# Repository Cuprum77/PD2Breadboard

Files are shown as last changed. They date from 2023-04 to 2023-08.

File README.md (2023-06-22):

# WORK IN PROGRESS - PD2Breadboard
Introducing the ultimate USB Power Delivery (PD) negotiator with unparalleled power measuring capabilities, powered by the cutting-edge RP2040 microcontroller. This isn't just any negotiator – it's a powerful variable power supply that's perfect for powering your breadboard projects on the fly, with an onboard high-resolution graphical LCD and three-button interface for easy control.

Our RP2040 powered USB PD negotiator is the perfect solution for anyone looking for a versatile, on-the-go power supply for their breadboard projects. With its advanced negotiating algorithm, this negotiator ensures optimal power delivery to your projects, while its onboard power measuring capabilities provide detailed insights into your device's power consumption.

The onboard high-resolution graphical LCD and three-button interface make it easy to control and monitor your device's power usage. With the graphical LCD, you can quickly view your device's power consumption and adjust the voltage levels to your desired level with the three-button interface.

Whether you're prototyping a new project, experimenting with electronics, or just need a reliable power source for your breadboard, our negotiator has you covered. It's capable of delivering up to 100W of power, with adjustable voltage levels ranging from 3.3V to 20V, making it compatible with a wide range of projects and devices.

And with its onboard power measuring capabilities, you'll have unprecedented insights into your device's power consumption. This feature is especially useful for those looking to optimize their device's power usage, or for those who want to monitor the power consumption of their projects in real-time.

Our RP2040 powered USB PD negotiator is also incredibly easy to use. Simply plug it into your USB port, set the voltage to your desired level using the graphical LCD and three-button interface, and let it power your breadboard project with ease. And with its compact, lightweight design, you can take it with you anywhere you go.

So why settle for a limited, fixed power supply when you can have the ultimate USB PD negotiator with onboard power measuring capabilities, variable voltage levels, and an onboard high-resolution graphical LCD and three-button interface? Take your breadboard projects to the next level!

## Technical Specifications
- RP2040 microcontroller
- 3.3V to 21V adjustable voltage levels[^1]
- 100W maximum power output[^2]
- 1.47" high-resolution graphical LCD
- 3-button interface
- USB Type-C connector
- Serial interface

[^1]: Requires a PPS capable device. The voltage levels are dependent on the power supply's capabilities.
[^2]: The maximum power output is dependent on the power supply's capabilities.

## Structure
### [Hardware](Hardware/)
The hardware folder contains all the hardware files for the project. This includes the schematic, PCB layout, and the BOM.
### [Resources](Resources/)
The resources folder contains all the resources for the project. This includes the datasheets, the user manuals, and the application notes. As well as images and other files that are used in the documentation.
### [Software/Embedded](Software/Embedded/)
The Folder contains all the software files for the microcontroller. This includes the source code, the libraries, and the relevant documentation.
### [Software/PC](Software/PC/)
The folder contains all the software files for the PC control program. This includes the source code, the libraries, and the relevant documentation.

## License
### Hardware
This hardware is licensed under the CERN Open Hardware Licence v2 - see the [LICENSE](Hardware/Rev%201/LICENSE) file for details
### Software
This software is licensed under the MIT License - see the [LICENSE](Software/Embedded/LICENSE) file for details

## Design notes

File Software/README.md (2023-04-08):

# PD2Breadboard Software
The RP2040 powered USB PD negotiator is not only a powerful variable power supply, but it also comes with a suite of advanced software features that set it apart from the competition. With power monitoring, self-diagnostics, and advanced algorithms, our software takes your breadboard projects to the next level.

The power monitoring feature allows you to keep an eye on your device's power consumption in real-time, providing detailed insights into your device's power usage. This feature is especially useful for those looking to optimize their device's power usage or for those who want to monitor the power consumption of their projects.

Our self-diagnostics feature ensures that your RP2040 powered USB PD negotiator is always functioning at peak performance. If any issues are detected, the software will provide detailed feedback, making it easy to diagnose and resolve any issues.

In addition to these features, our software is designed with ease of use in mind. The graphical user interface is intuitive and easy to navigate, making it easy to adjust the voltage levels and monitor power usage. And with its lightweight design, you can take it with you anywhere you go.

## Build
### Provided binaries
The provided binaries are located in the [build](build/) folder. The binaries are in the UF2 format, which can be flashed to the Pico using one of the two methods below.

### Programming via script
Dependencies:
* [Python 3](https://www.python.org/downloads/)

To build the project, simply run the `programmer.py` either using python or simply clicking the `programmer.bat` file if you are on Windows. The script will automatically install its own dependencies and transfer the code to the Pico.

### Programming manually
To program the pico there are two manual options

Using a Serial terminal:
* Using Serial to transmit the string "reset" will automatically put it in USB boot mode
* Manually drag and drop the UF2 file into the Pico drive from the build folder
Using the BOOTSEL button:
* Remove power from the Pico
* Press and hold the BOOTSEL button
* Reapply power to the Pico
* Release the BOOTSEL button
* Drag and drop the UF2 file into the Pico drive from the build folder

### Manually build the project
Dependencies:
* [VSCode](https://code.visualstudio.com/download)
* SDK [Windows](https://github.com/raspberrypi/pico-setup-windows/releases/latest/download/pico-setup-windows-x64-standalone.exe) | [Linux](https://github.com/raspberrypi/pico-sdk)

Follow the instructions on the SDK page to install the SDK. After installing the SDK, open the project in VSCode and build the project.

## Known Errors
### Version 1.0.0
* The debounce circuit, is supposed to form an RC circuit, but the pull-up resistor is placed on the wrong side of the current limiting resistor forming a voltage divider rather than an RC circuit. This means that the debounce circuit is not working as intended.
* Shunt resistor is too low value, this means we cannot get readings below 10mA. 

## License
This software is licensed under the MIT License - see the [LICENSE](LICENSE) file for details

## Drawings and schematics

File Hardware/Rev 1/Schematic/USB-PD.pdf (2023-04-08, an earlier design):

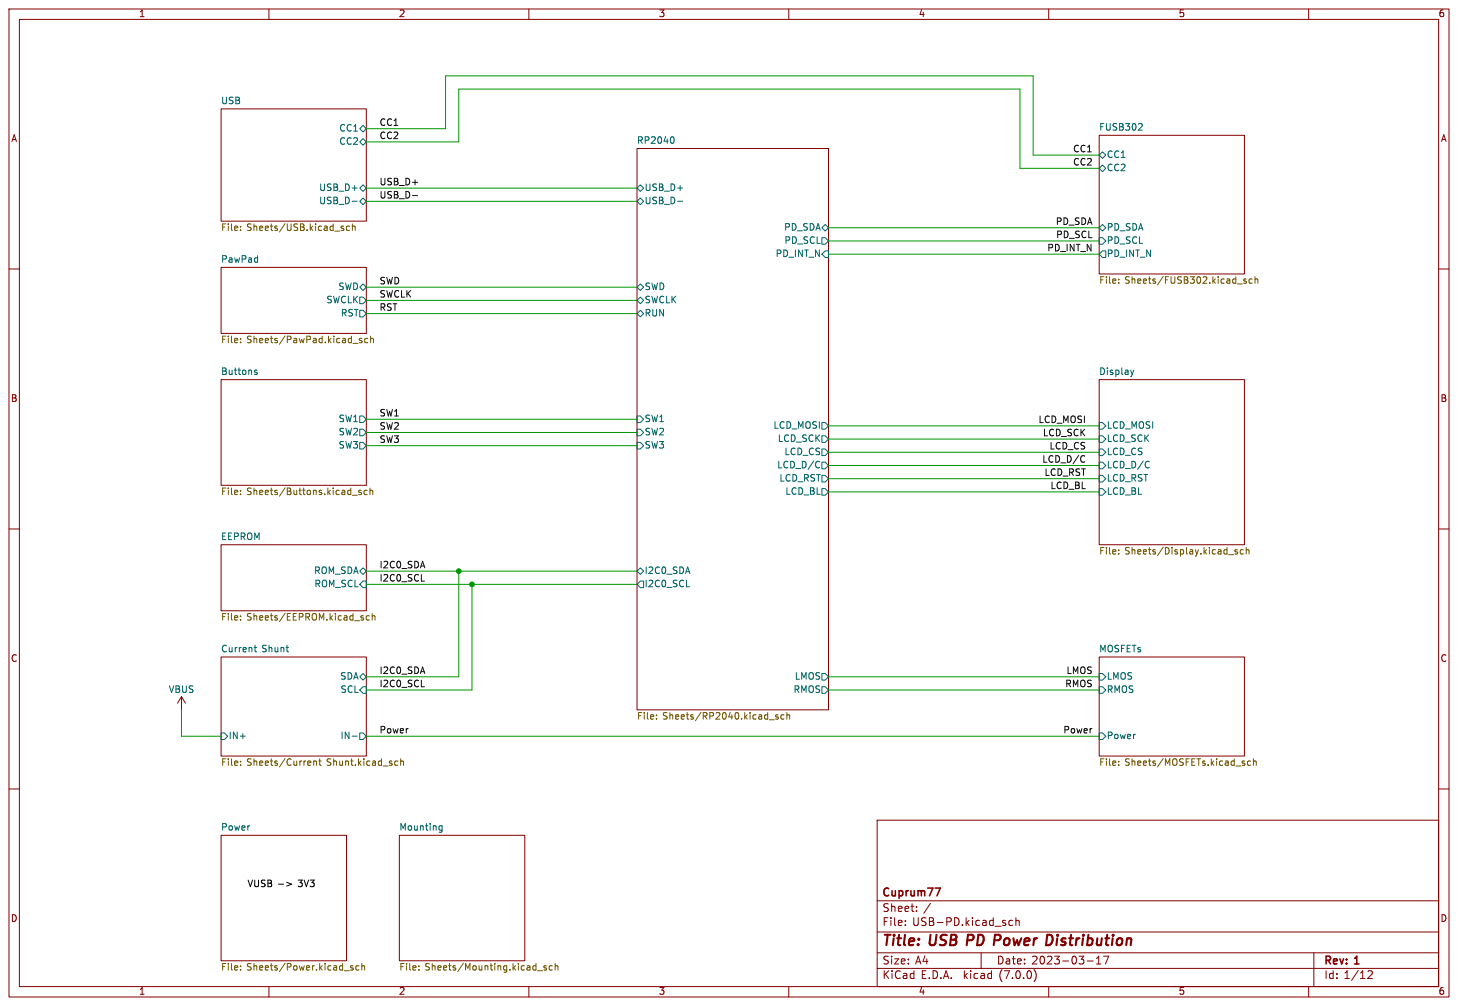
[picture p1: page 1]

SW3 SW2 SW1 Buttons File: Sheets/Buttons.kicad_sch USB_D- USB_D+ CC2 CC1 USB
LMOS RMOS RUN

RP2040 File: Sheets/RP2040.kicad_sch Power File: Sheets/Power.kicad_sch

Display File: Sheets/Display.kicad_sch SWD

File: Sheets/EEPROM.kicad_sch VBUS

Power MOSFETs File: Sheets/MOSFETs.kicad_sch

File: USB-PD.kicad_sch Sheet: / Cuprum77

Id: 1/12 Title: USB PD Power Distribution

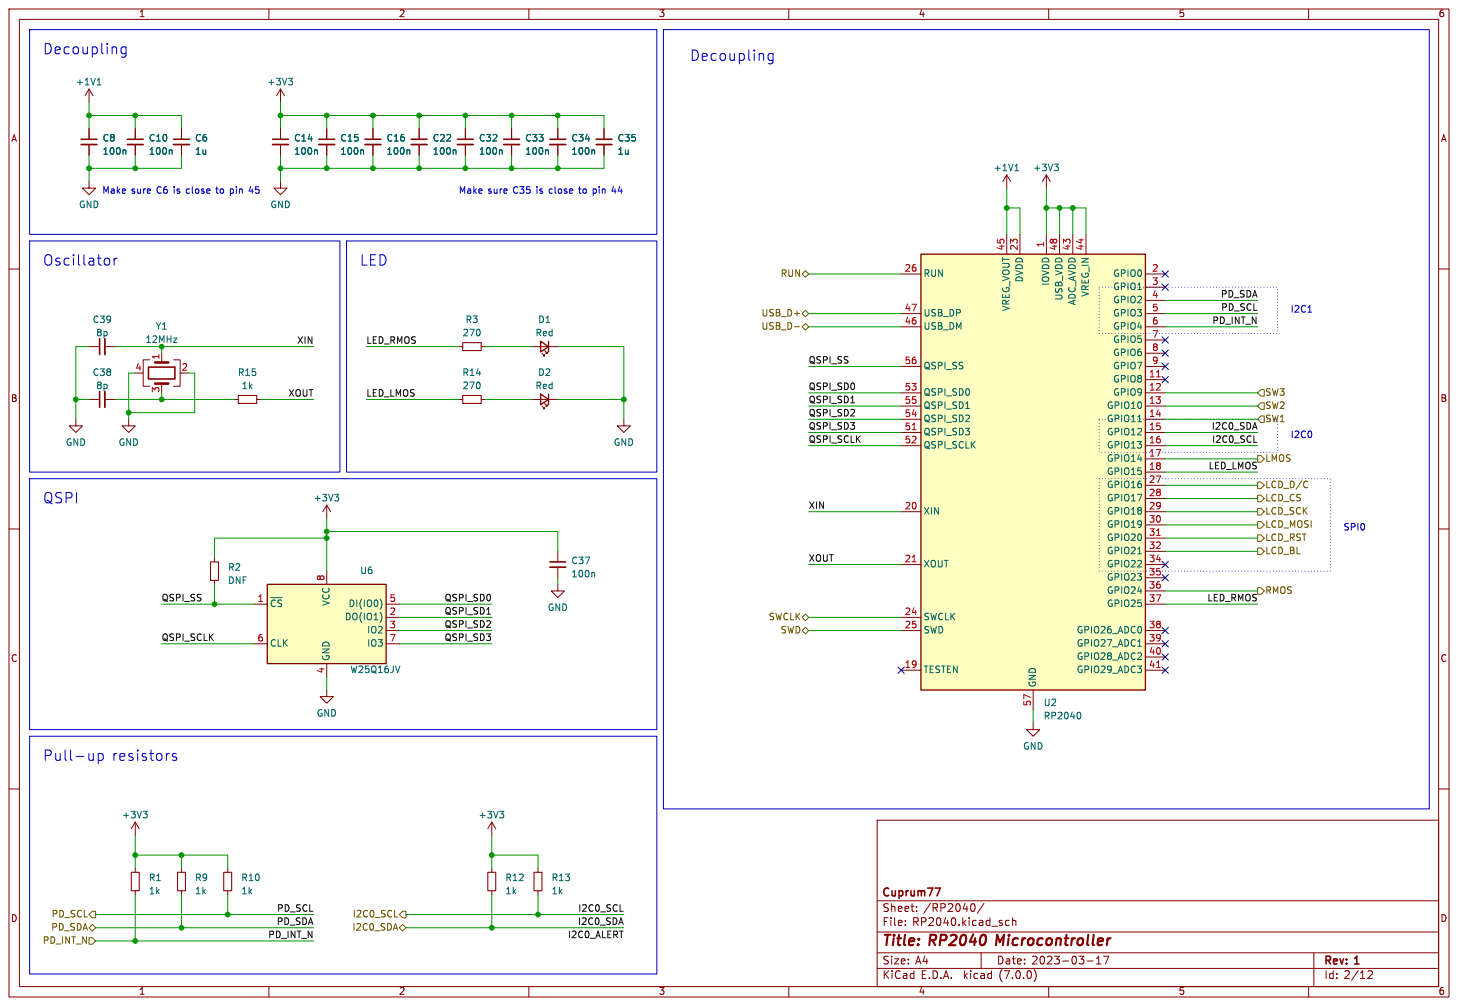
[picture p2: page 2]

1 GPIO8 11 GPIO9 12 GPIO10 13 GPIO11 14 GPIO12 15 GPIO13 16 GPIO14 17 GPIO15 18 TESTEN 19 GPIO0 2 XIN 20 XOUT 21 DVDD 23 SWCLK 24 SWD 25 RUN 26 GPIO16 27 GPIO17 28 GPIO18 29 GPIO1 3 GPIO19 30 GPIO20 31 GPIO21 32 GPIO22 34 GPIO23 35 GPIO24 36 GPIO25 37 GPIO26_ADC0 38 GPIO27_ADC1 39 GPIO2 4 GPIO28_ADC2 40 GPIO29_ADC3 41 ADC_AVDD 43 VREG_IN 44 VREG_VOUT 45 USB_DM 46 USB_DP 47 USB_VDD 48 GPIO3 5 QSPI_SD3 51 QSPI_SCLK 52 QSPI_SD0 53 QSPI_SD2 54 QSPI_SD1 55 QSPI_SS 56 GND 57 GPIO4 6 GPIO5 7 GPIO6 8 GPIO7 9 U2 RP2040

Id: 2/12 Title: RP2040 Microcontroller File: RP2040.kicad_sch Sheet: /RP2040/ Cuprum77

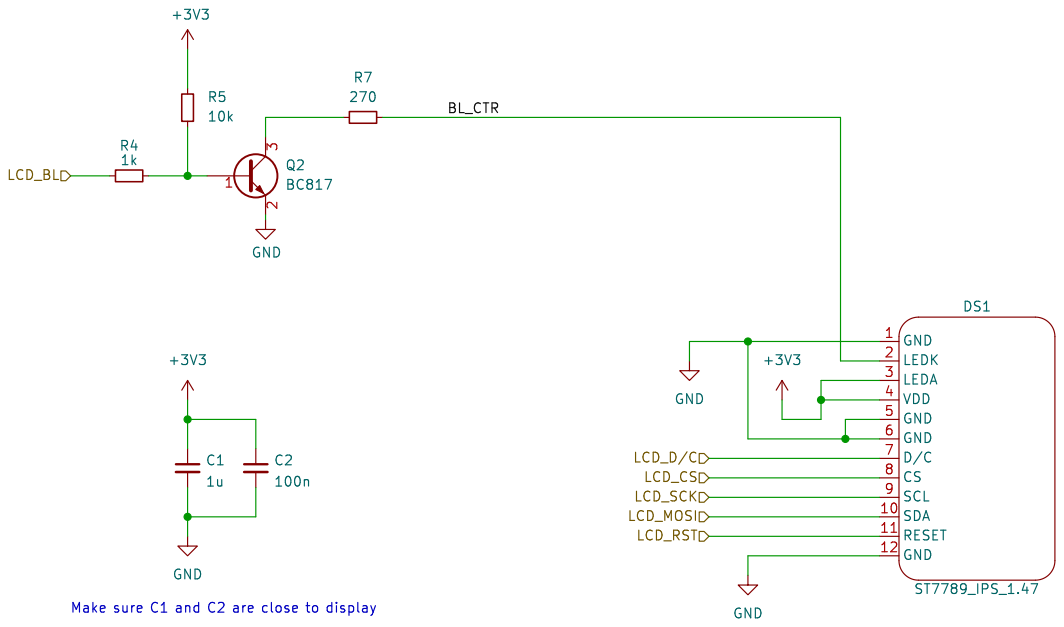
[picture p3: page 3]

LCD_RST BL_CTR Make sure C1 and C2 are close to display

Cuprum77
File: Display.kicad_sch Sheet: /Display/
Id: 3/12 Title: LCD Display

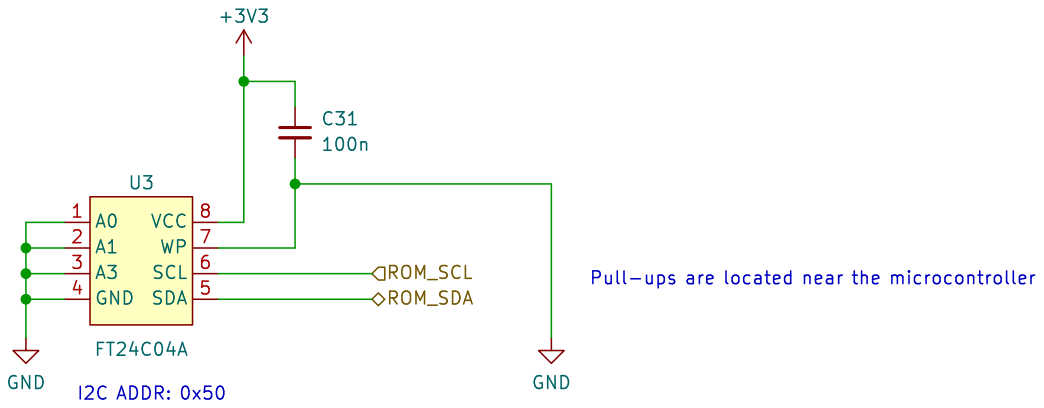
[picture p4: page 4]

File: EEPROM.kicad_sch Sheet: /EEPROM/ Cuprum77

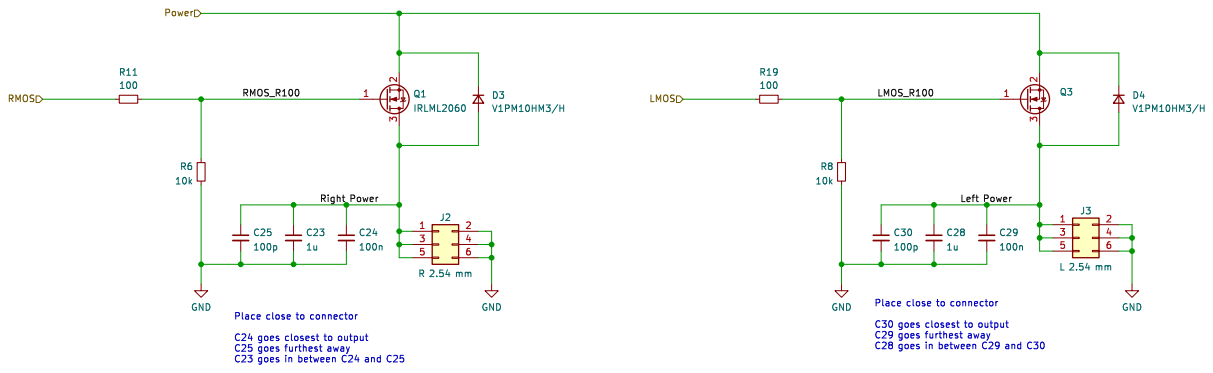
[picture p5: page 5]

Id: 5/12 Title: Output Control File: MOSFETs.kicad_sch Sheet: /MOSFETs/ Cuprum77

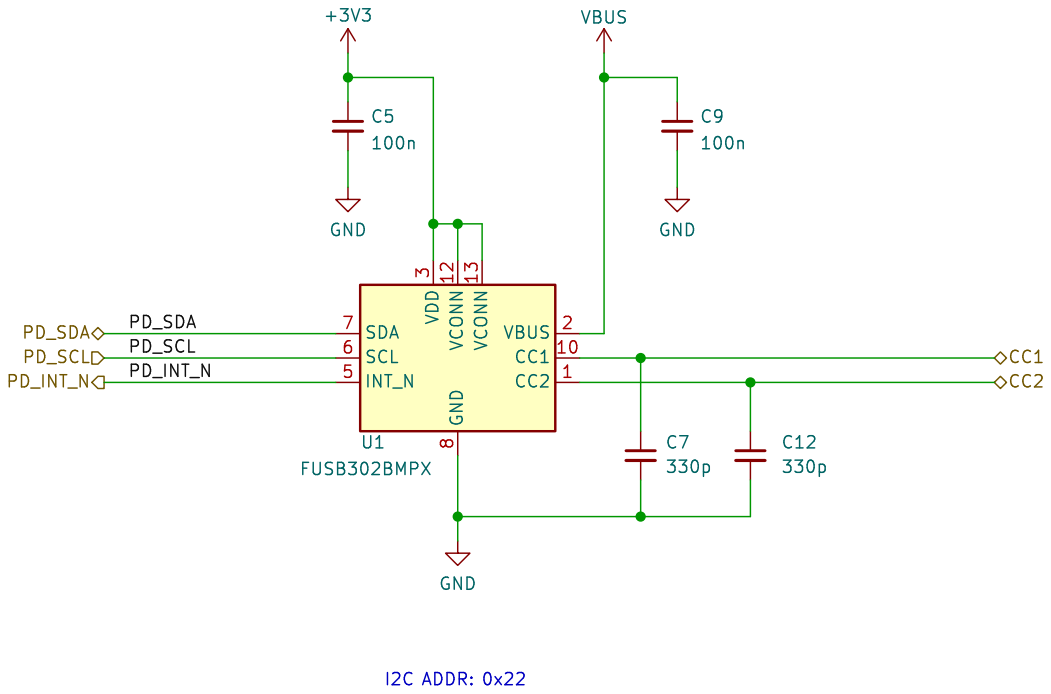
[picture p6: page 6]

Id: 6/12 Title: USB PD Interface

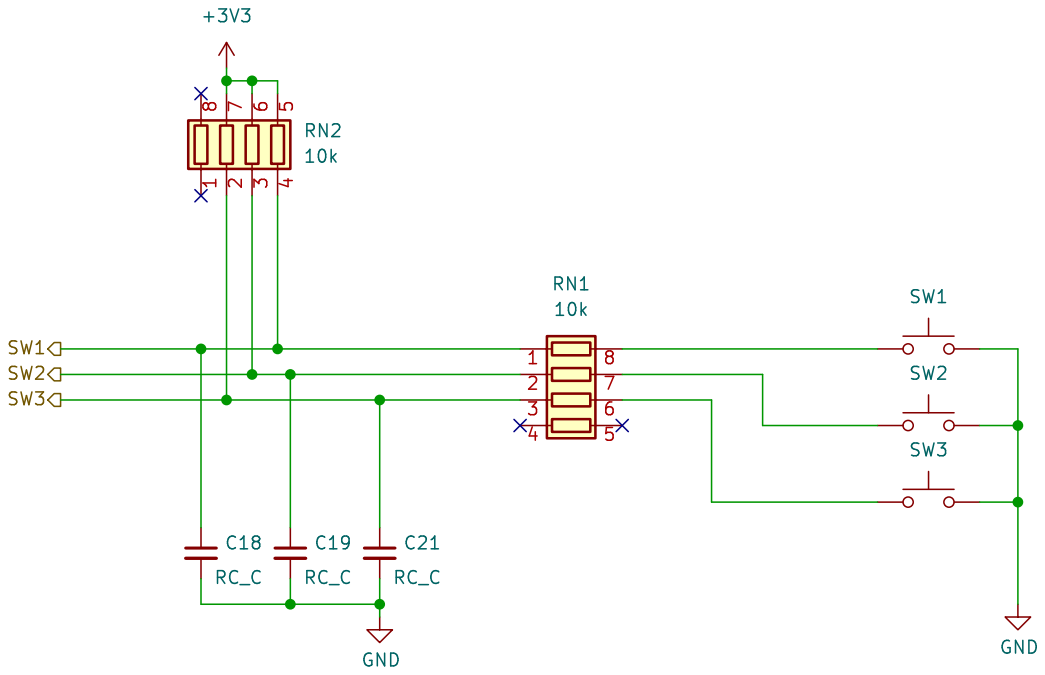
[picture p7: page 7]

File: Buttons.kicad_sch Sheet: /Buttons/ Cuprum77 GND

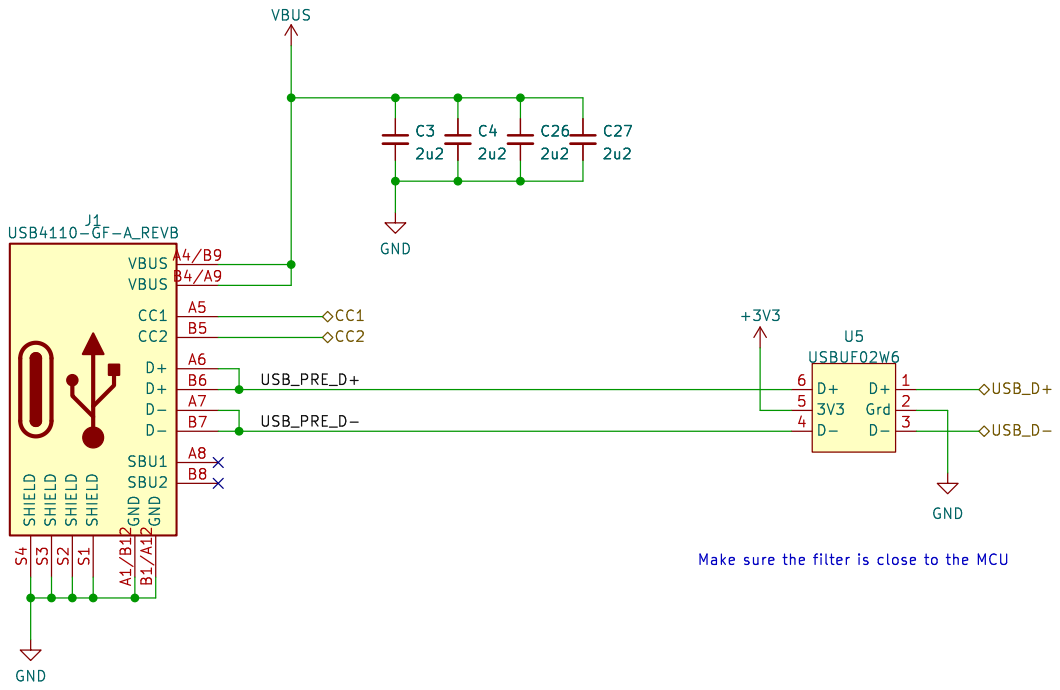
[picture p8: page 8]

File: USB.kicad_sch Sheet: /USB/ Cuprum77 GND

Id: 8/12 Title: USB Interface

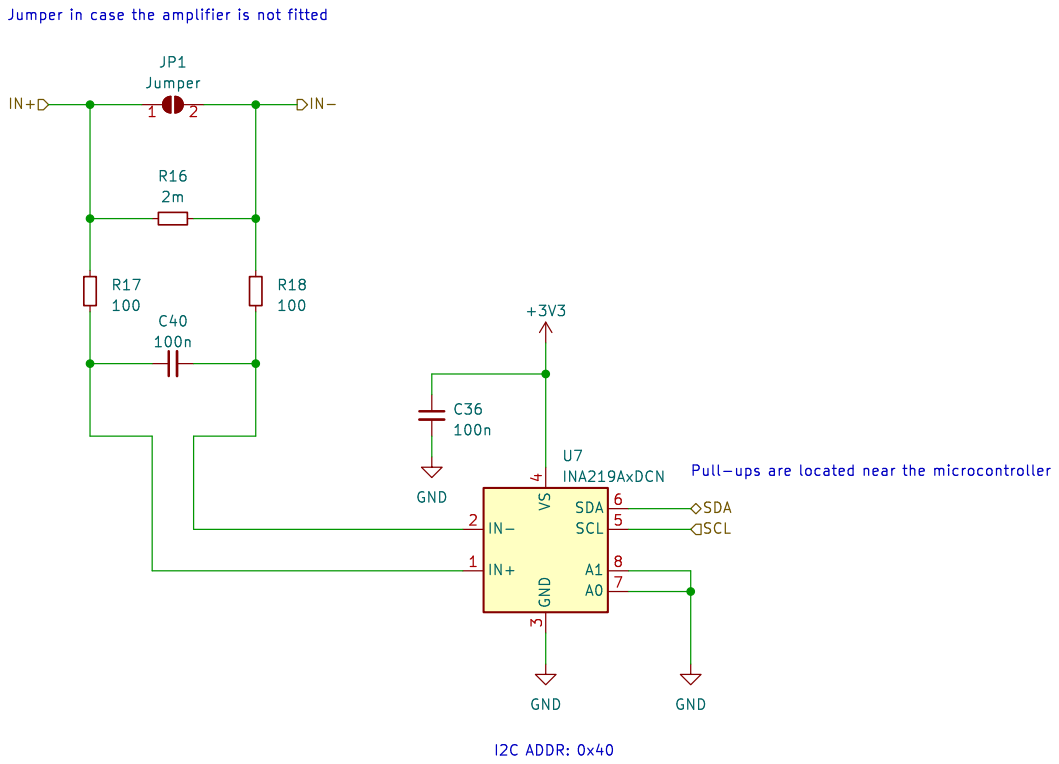
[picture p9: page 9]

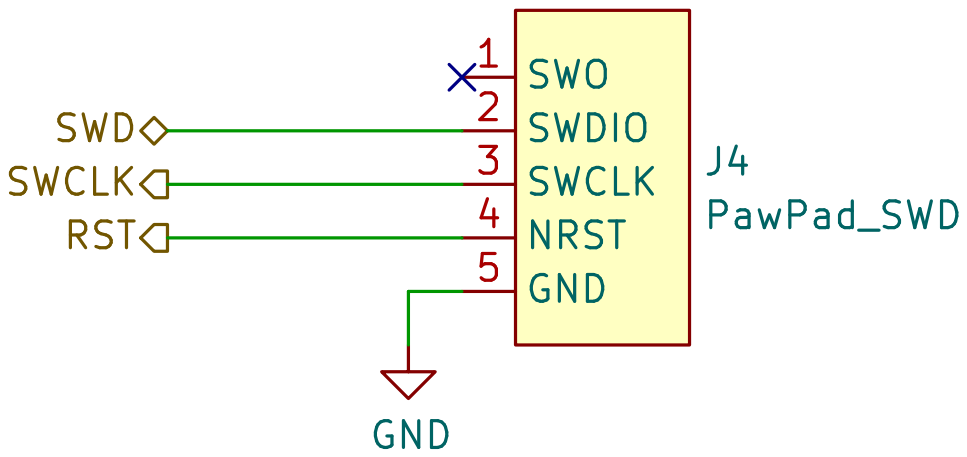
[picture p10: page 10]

File: PawPad.kicad_sch Sheet: /PawPad/ Cuprum77

Id: 10/12 Title: SWD Interface

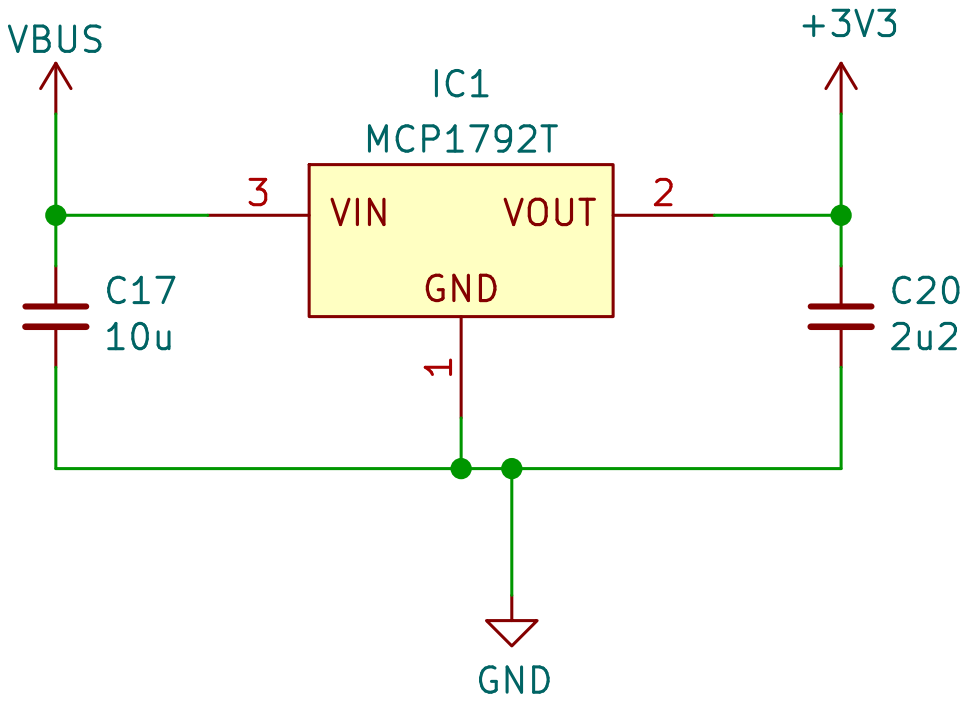
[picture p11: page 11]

File: Power.kicad_sch Sheet: /Power/ Cuprum77 C20

Id: 11/12 Title: LDO Power Supply

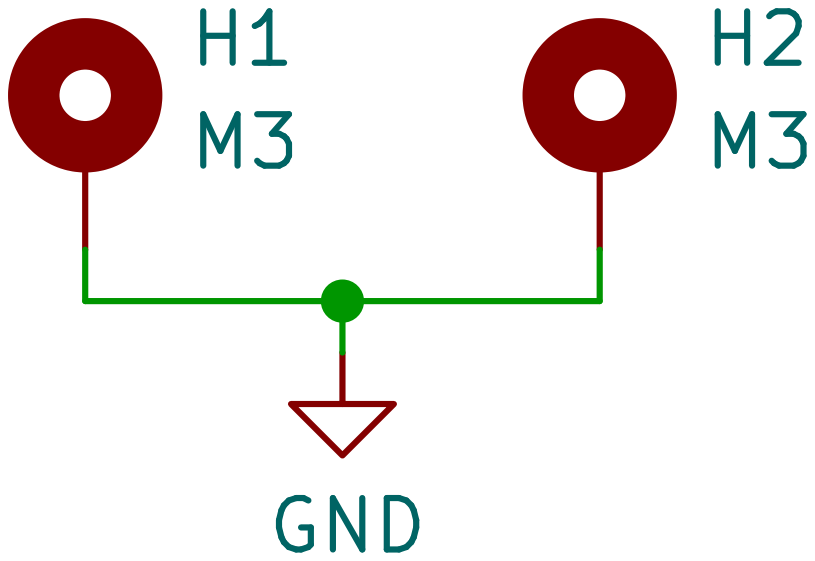
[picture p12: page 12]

File: Mounting.kicad_sch Sheet: /Mounting/
Id: 12/12 Title: Mounting Holes

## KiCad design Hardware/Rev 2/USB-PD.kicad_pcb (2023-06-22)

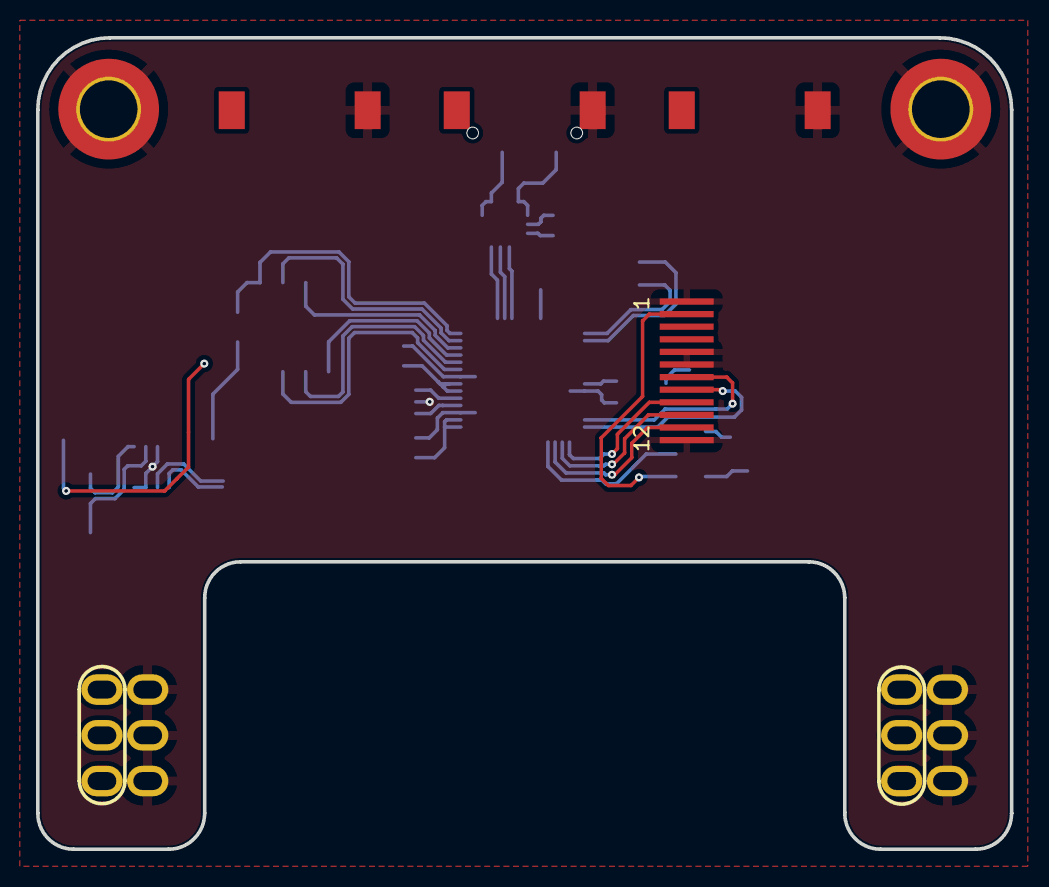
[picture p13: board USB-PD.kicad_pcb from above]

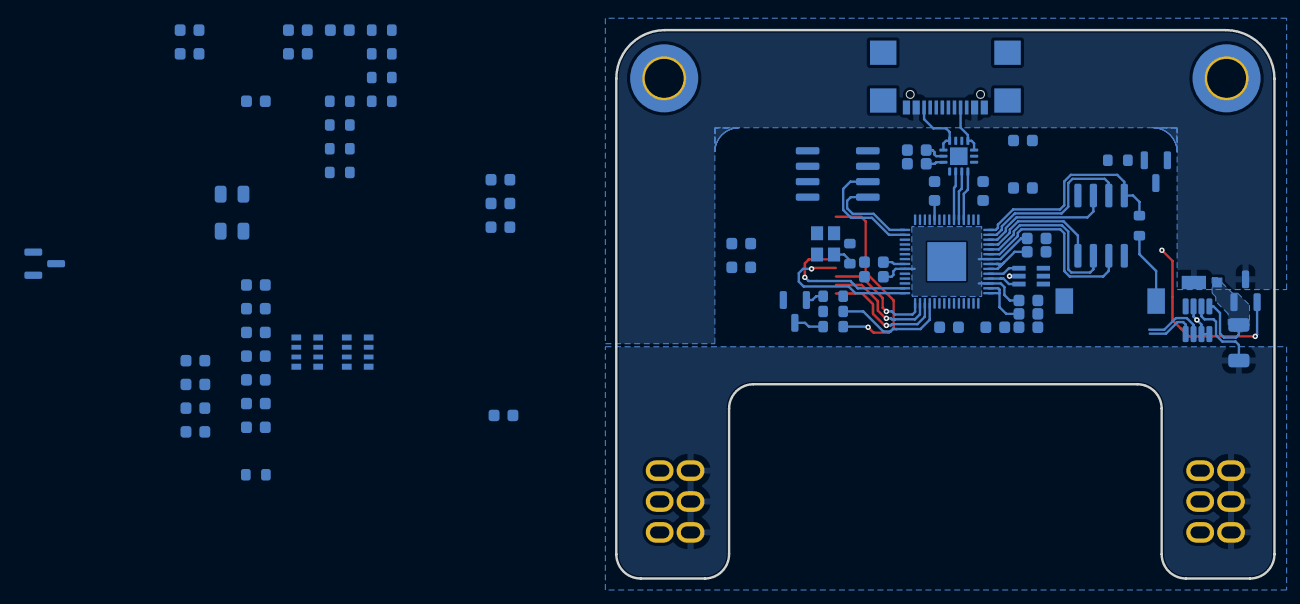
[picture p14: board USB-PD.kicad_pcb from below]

Board: 2 copper layers, 54.1 x 45.1 mm, 80 parts (72 on the bottom side), 49 nets.

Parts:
C1, C6, C23, C28, C35: 1u; C_0603_1608Metric
C2, C5, C8, C9, C10, C13, C14, C15, C16, C22, C24, C29, C31, C32, C33, C34, C37: 100n; C_0603_1608Metric
C3, C4, C17, C20, C26, C27: 2u2; C_0603_1608Metric
C7, C12: 330p; C_0603_1608Metric
C11: 10u; C_0603_1608Metric
C18, C19, C21: RC_C; C_0603_1608Metric
C25, C30: 100p; C_0603_1608Metric
C38, C39: 8p; C_0603_1608Metric
D1, D2: Pink; D_0805_2012Metric
D3: V1PM10HM3/H; V1PM10HM3H
DS1: ST7789_IPS_1.47; 1.47 inch 12PIN ST7789
H1, H2: M3; MountingHole_3.2mm_M3_DIN965_Pad_TopBottom
IC1: MCP1792T; SOT-23
J1: USB4110-GF-A_REVB; GCT_USB4110-GF-A_REVB
J2: R 2.54 mm; PinHeader_2x03_P2.54mm_Vertical_Elongated
J3: L 2.54 mm; PinHeader_2x03_P2.54mm_Vertical_Elongated
Q1: PMOS; SOT-23
Q2: BC817; SOT-23
Q3: BC317; SOT-23
R1, R4, R9, R10, R12, R13, R15: 1k; R_0603_1608Metric
R2, R16: DNF; R_0603_1608Metric
R3, R14: 270; R_0603_1608Metric
R5, R8: 10k; R_0603_1608Metric
R6: 100; R_0603_1608Metric
R7: 60; R_0603_1608Metric
R17: 10m; R_1206_3216Metric
RN1, RN2: 10k; R_Array_Convex_4x0603
SW1: SW_MENU; PTS636 SM25J SMTR LFS
SW2: SW_DOWN; PTS636 SM25J SMTR LFS
SW3: SW_CONF; PTS636 SM25J SMTR LFS
SW4: DNF; PTS636 SM25J SMTR LFS
U1: FUSB302BMPX; WQFN-14-1EP_2.5x2.5mm_P0.5mm_EP1.45x1.45mm
U2: RP2040; QFN-56-1EP_7x7mm_P0.4mm_EP3.2x3.2mm
U3: FT24C04A; SOIC-8_3.9x4.9mm_P1.27mm
U4: INA219AxDCN; SOT-23-8
U5: USBUF02W6; SOT65P210X110-6N
U6: W25Q16JV; SOIC-8_3.9x4.9mm_P1.27mm
Y1: 12MHz; Crystal_SMD_2520-4Pin_2.5x2.0mm

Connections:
+1V1: C6.1, C8.1, C10.1, U2.23 (DVDD), U2.45 (VREG_VOUT), U2.50 (DVDD)
+3V3: C1.1, C2.1, C5.1, C13.1, C14.1, C15.1, C16.1, C17.1, C20.1, C22.1, C31.1, C32.1, C33.1, C34.1, C35.1, C37.1, DS1.3 (LEDA), DS1.4 (VDD), IC1.2, R1.2, R2.2, R5.2, R9.2, R10.2, R12.2, R13.2, RN2.5 (R4.2), RN2.6 (R3.2), RN2.7 (R2.2), U1.3 (VDD), U1.4 (VDD), U1.12 (VCONN), U1.13 (VCONN), U2.1 (IOVDD), U2.10 (IOVDD), U2.22 (IOVDD), U2.33 (IOVDD), U2.42 (IOVDD), U2.43 (ADC_AVDD), U2.44 (VREG_IN), U2.48 (USB_VDD), U2.49 (IOVDD), U3.8 (VCC), U4.4 (VS), U5.5 (3V3), U6.8 (VCC)
/CC1: C7.1, J1.A5 (CC1), U1.10 (CC1), U1.11 (CC1)
/CC2: C12.1, J1.B5 (CC2), U1.1 (CC2), U1.14 (CC2)
/Display/BL_CTR: DS1.2 (LEDK), R7.1
/I2C0_SCL: R13.1, U2.16 (GPIO13), U3.6 (SCL), U4.5 (SCL)
/I2C0_SDA: R12.1, U2.15 (GPIO12), U3.5 (SDA), U4.6 (SDA)
/LCD_BL: R4.1, U2.32 (GPIO21)
/LCD_CS: DS1.8 (CS), U2.28 (GPIO17)
/LCD_D/C: DS1.7 (D/C), U2.27 (GPIO16)
/LCD_MOSI: DS1.10 (SDA), U2.30 (GPIO19)
/LCD_RST: DS1.11 (RESET), U2.31 (GPIO20)
/LCD_SCK: DS1.9 (SCL), U2.29 (GPIO18)
/MOSFETs/POW_OUT: C23.1, C24.1, C25.1, C28.1, C29.1, C30.1, J2.1, J2.3, J2.5, J3.1, J3.3, J3.5, R17.2, U4.2 (IN-)
/PD_INT_N: R1.1, U1.5 (INT_N), U2.6 (GPIO4)
/PD_SCL: R10.1, U1.6 (SCL), U2.5 (GPIO3)
/PD_SDA: R9.1, U1.7 (SDA), U2.4 (GPIO2)
/RMOS: R6.1, U2.36 (GPIO24)
/RP2040/LED_LMOS: R14.2, U2.18 (GPIO15)
/RP2040/LED_RMOS: R3.2, U2.37 (GPIO25)
/RP2040/QSPI_SCLK: U2.52 (QSPI_SCLK), U6.6 (CLK)
/RP2040/QSPI_SD0: U2.53 (QSPI_SD0), U6.5 (DI(IO0))
/RP2040/QSPI_SD1: U2.55 (QSPI_SD1), U6.2 (DO(IO1))
/RP2040/QSPI_SD2: U2.54 (QSPI_SD2), U6.3 (IO2)
/RP2040/QSPI_SD3: U2.51 (QSPI_SD3), U6.7 (IO3)
/RP2040/QSPI_SS: R2.1, R16.1, U2.56 (QSPI_SS), U6.1 (~CS)
/RP2040/XIN: C39.2, U2.20 (XIN), Y1.1
/RP2040/XOUT: R15.1, U2.21 (XOUT)
/SW1: RN1.1 (R1.1), U2.14 (GPIO11)
/SW2: RN1.2 (R2.1), U2.13 (GPIO10)
/SW3: RN1.3 (R3.1), U2.12 (GPIO9)
/USB/USB_PRE_D+: J1.A6 (D+), J1.B6 (D+), U5.6 (D+)
/USB/USB_PRE_D-: J1.A7 (D-), J1.B7 (D-), U5.4 (D-)
/USB_D+: U2.47 (USB_DP), U5.1 (D+)
/USB_D-: U2.46 (USB_DM), U5.3 (D-)
GND: C1.2, C2.2, C3.2, C4.2, C5.2, C6.2, C7.2, C8.2, C9.2, C10.2, C11.2, C12.2, C13.2, C14.2, C15.2, C16.2, C17.2, C18.2, C19.2, C20.2, C21.2, C22.2, C23.2, C24.2, C25.2, C26.2, C27.2, C28.2, C29.2, C30.2, C31.2, C32.2, C33.2, C34.2, C35.2, C37.2, C38.1, C39.1, D1.1 (K), D2.1 (K), DS1.1 (GND), DS1.5 (GND), DS1.6 (GND), DS1.12 (GND), H1.1, H2.1, IC1.1, J1.A1/B12 (GND), J1.B1/A12 (GND), J1.S1 (SHIELD), J1.S2 (SHIELD), J1.S3 (SHIELD), J1.S4 (SHIELD), J2.2, J2.4, J2.6, J3.2, J3.4, J3.6, Q2.2 (E), Q3.1 (E), SW1.2, SW2.2, SW3.2, SW4.1, U1.8 (GND), U1.9 (GND), U1.15 (GND), U2.57 (GND), U3.1 (A0), U3.2 (A1), U3.3 (A3), U3.4 (GND), U3.7 (WP), U4.3 (GND), U4.7 (A0), U4.8 (A1), U5.2 (Grd), U6.4 (GND), Y1.2, Y1.4
unnamed: C38.2, R15.2, Y1.3
unnamed: D1.2 (A), R3.1
unnamed: D2.2 (A), R14.1
unnamed: D3.2 (A), Q1.1 (D), R17.1, U4.1 (IN+)
unnamed: Q1.2 (G), Q3.3 (C), R8.2
unnamed: Q2.1 (B), R4.2, R5.1
unnamed: Q2.3 (C), R7.2
unnamed: Q3.2 (B), R6.2
unnamed: R16.2, SW4.2
unnamed: C18.1, RN1.8 (R1.2), RN2.4 (R4.1), SW1.1
unnamed: C19.1, RN1.7 (R2.2), RN2.3 (R3.1), SW2.1
unnamed: C21.1, RN1.6 (R3.2), RN2.2 (R2.1), SW3.1
VBUS: C3.1, C4.1, C9.1, C11.1, C26.1, C27.1, D3.1 (K), IC1.3, J1.A4/B9 (VBUS), J1.B4/A9 (VBUS), Q1.3 (S), R8.1, U1.2 (VBUS)

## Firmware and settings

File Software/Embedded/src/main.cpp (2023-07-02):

#include "include/Defines.hpp"

// set the variables to the default values in case we fail to retrieve the data from the EEPROM
unsigned int currentNegotiated = Device_Target_Current_Default;
unsigned int voltageNegotiated = Device_Target_Voltage_Default;
unsigned int currentLimit = PFuse_Trip_Current_Default;
unsigned int backlightBrightness = Display_Brightness_Default;

// overcurrent boolean
bool overcurrent = false;
bool outputEnabled = false;

// pps variables
bool ppsReady = false;
float maxCurrent = 0;
float maxVoltage = 0;
PD_power_option_t PDList[] = {
	PD_POWER_OPTION_MAX_5V, 
	PD_POWER_OPTION_MAX_9V, 
	PD_POWER_OPTION_MAX_12V, 
	PD_POWER_OPTION_MAX_15V, 
	PD_POWER_OPTION_MAX_20V
};

// set the display parameters
// the ifdefs are used to prevent the intellisense from complaining about the variables not being defined
Display_Pins displayPins = {
#ifndef __INTELLISENSE__
	.rst = DISP_PIN_RST,
	.dc = DISP_PIN_DC,
	.cs = DISP_PIN_CS,
	.sda = DISP_PIN_MOSI,
	.scl = DISP_PIN_SCK,
	.bl = DISP_PIN_BL
#endif
};

Display_Params displayParams = {
#ifndef __INTELLISENSE__
	.interface = SPI_Interface_t::PIO_HW,
	.type = display_type_t::ST7789,
	.height = DISP_HEIGHT,
	.width = DISP_WIDTH,
	.columnOffset1 = DISP_OFFSET_X0,
	.columnOffset2 = DISP_OFFSET_X1,
	.rowOffset1 = DISP_OFFSET_Y0,
	.rowOffset2 = DISP_OFFSET_Y1,
	.rotation = DISP_ROTATION
#endif
};

// Create the display object
HardwareSPI spi(displayPins, displayParams);
Display display(&spi, &displayPins, &displayParams);
// Create the GFX objects
Print print(display.getFrameBuffer(), displayParams);
Graphics graphics(display.getFrameBuffer(), displayParams);
AdvancedGraphics advancedGraphics(display.getFrameBuffer(), displayParams);
// Create the PicoGFX object
PicoGFX picoGFX(&display, &print, &graphics, &advancedGraphics);

// Create the objects
Button buttonUp(BUTTON_UP);
Button buttonMenu(BUTTON_MENU);
Button buttonDown(BUTTON_DOWN);
Memory memory(EEPROM_ADDRESS, i2c0);
INA219 ina219(INA219_ADDRESS, i2c0);
Registers registers;
PD_UFP_log_c PD_UFP(PD_LOG_LEVEL_VERBOSE);

/**
 * @brief Initialize the I2C busses
*/
void initI2C()
{
	// initialize the I2C0 bus
	gpio_set_function(I2C0_SDA, GPIO_FUNC_I2C);
	gpio_set_function(I2C0_SCL, GPIO_FUNC_I2C);
	gpio_pull_up(I2C0_SDA);
	gpio_pull_up(I2C0_SCL);
	i2c_init(i2c0, I2C0_SPEED);
	// set the binary data to show the pins used for I2C0
	bi_decl(bi_2pins_with_func(I2C0_SDA, I2C0_SCL, GPIO_FUNC_I2C));

	// initialize the I2C1 bus
	gpio_set_function(I2C1_SDA, GPIO_FUNC_I2C);
	gpio_set_function(I2C1_SCL, GPIO_FUNC_I2C);
	gpio_pull_up(I2C1_SDA);
	gpio_pull_up(I2C1_SCL);
	i2c_init(i2c1, I2C1_SPEED);
	// set the binary data to show the pins used for I2C1
	bi_decl(bi_2pins_with_func(I2C1_SDA, I2C1_SCL, GPIO_FUNC_I2C));
}

/**
 * @brief Initialize the LEDs
*/
void initLEDs()
{
	// init the pins
	gpio_init(LEFT_MOSFET_LED);
	gpio_init(RIGHT_MOSFET_LED);
	gpio_init(LEFT_MOSFET);
	gpio_init(RIGHT_MOSFET);

	// set the pins to output
	gpio_set_dir(LEFT_MOSFET_LED, GPIO_OUT);
	gpio_set_dir(RIGHT_MOSFET_LED, GPIO_OUT);
	gpio_set_dir(LEFT_MOSFET, GPIO_OUT);
	gpio_set_dir(RIGHT_MOSFET, GPIO_OUT);

	// set mosfet to high to disable the output
	gpio_put(LEFT_MOSFET, 1);
	gpio_put(RIGHT_MOSFET, 1);

	// set the binary data to show the pins used for the LEDs
	bi_decl(bi_4pins_with_names(
		LEFT_MOSFET_LED, "Left MOSFET LED", 
		LEFT_MOSFET, "Left MOSFET", 
		RIGHT_MOSFET_LED, "Right MOSFET LED", 
		RIGHT_MOSFET, "Right MOSFET")
	);
}

/**
 * @brief Get the data from the EEPROM
*/
void fetchDataFromEEPROM()
{
	// verify that the EEPROM is connected
	if(!memory.verifyConnection())
	{
		// eeprom not found, revert to default values
		printf("EEPROM not found!\n");
		return;
	}

	// eeprom found, fetch the values
	currentNegotiated = memory.readWord(MEMORY_CURRENT_ADDRESS);
	voltageNegotiated = memory.readWord(MEMORY_VOLTAGE_ADDRESS);
	currentLimit = memory.readWord(MEMORY_CURRENT_LIMIT_ADDRESS);
	backlightBrightness = memory.readWord(MEMORY_BACKLIGHT_ADDRESS);
}

// pattern data
unsigned long lastWarningBlink = 0;
bool ledStates = false;
const long blinkIntervalSequence[4] = { 100000, 62500, 100000, 600000};
/**
 * @brief Blink both LEDs on the board in a pattern if the current is too high!
 * @note Has to be called every loop
*/
void overCurrentLEDs()
{
	static int overCurrentSequenceIndex = 0;

	// if we are not over current, reset the sequence index
	if(!overcurrent && ledStates)
	{
		ledStates = false;
		overCurrentSequenceIndex = 0;
		gpio_put(LEFT_MOSFET_LED, ledStates);
		gpio_put(RIGHT_MOSFET_LED, ledStates);
	}

	// if we havent reached our current interval yet, return
	if(((time_us_32() - lastWarningBlink) < blinkIntervalSequence[overCurrentSequenceIndex]) || !overcurrent)
		return;
	
	// increment the sequence index
	overCurrentSequenceIndex++;

	// if we have reached the end of the sequence, reset the index
	if(overCurrentSequenceIndex > 3)
		overCurrentSequenceIndex = 0;

	// toggle the LED
	gpio_put(LEFT_MOSFET_LED, ledStates);
	gpio_put(RIGHT_MOSFET_LED, ledStates);
	// set the last debounce time
	lastWarningBlink = time_us_32();
	ledStates = !ledStates;
}

/**
 * @brief Handle the register access from writing to them or reading from them
 * @note Has to be called every loop
 * @param all If true, all registers will be handled, if false, only the ones that have changed will be handled
*/
void RegisterHandler(bool all = false)
{
	if(all)
	{
		if(registers.getProtected(Register_Address::Device_Reboot_Bootloader))
		{
			// reset the device into bootloader mode
			// the intellisense doesnt like this function so we have to disable it until we build
#ifndef __INTELLISENSE__
			multicore_reset_core1();
			reset_usb_boot(0, 0);
			while(1);
#endif			
		}
		if(registers.getProtected(Register_Address::Device_Reset))
		{
			watchdog_reboot(0, SRAM_END, 0);
			while(1);
		}
		if(registers.getProtected(Register_Address::Device_Self_Test))
		{
		}
	}
	else
	{

	}
}

// empty buffer to store the data
char buffer[8] = {0};
/**
 * @brief Process the USB data
 * @note Has to be called every loop
 */
void processUSBData()
{
	// check if the USB has data for us, if not, return
	if(!tud_cdc_available())
		return;

	// read the data from the USB
	tud_cdc_read(buffer, 7);

	/*
		The new protocol works as follows:
		- The first character indicates read or write (0 = read, 1 = write)
		- The second character is the address
		(IF WRITING)
		{
			(IF ARRAY)
			- The third character is the index
			- The next 4 characters are the data
			(IF SINGLE)
			- The next 4 characters are the data
		}
		(IF READING)
		{
			(IF ARRAY)
			- The third character is the index
			- Return the data
			(IF SINGLE)
			- Return the data
		}
	*/

	// check if we are reading or writing
	bool isWrite = buffer[0] != 0;

	// are we writing?
	if(isWrite)
	{
		// is it an array?
		if(registers.isArray((Register_Address)buffer[1]))
		{
			unsigned int index = buffer[2];
			unsigned int data = buffer[3] << 24 | buffer[4] << 16 | buffer[5] << 8 | buffer[6];
			// write the data to the array
			registers.set((Register_Address)buffer[1], index, data);
		}
		else
		{
			unsigned int data = buffer[2] << 24 | buffer[3] << 16 | buffer[4] << 8 | buffer[5];
			// write the data to the register
			registers.set((Register_Address)buffer[1], data);
		}

		// go through all the registers to act on change
		RegisterHandler(true);
	}
	else
	{
		// is it an array?
		if(registers.isArray((Register_Address)buffer[1]))
		{
			unsigned int index = buffer[2];
			// read the data from the array
			unsigned int data = registers.get((Register_Address)buffer[1], index);
			// send the data back
			printf("%d\n", data);
		}
		else
		{
			// read the data from the register
			unsigned int data = registers.get((Register_Address)buffer[1]);
			// send the data back
			printf("%d\n", data);
		}
	}

	// clear the buffer
	memset(buffer, 0, sizeof(buffer));
}


/**
 * @brief Button handler
 * @note Has to be called every loop
*/
void buttonHandler()
{
	if(buttonMenu.isHeld())
	{
		static bool state = true;
		state = !state;
		gpio_put(LEFT_MOSFET, !state);
		gpio_put(RIGHT_MOSFET, !state);
		gpio_put(LEFT_MOSFET_LED, state);
		gpio_put(RIGHT_MOSFET_LED, state);
		printf("MENU held\n");
	}

	buttonUp.update();
	buttonMenu.update();
	buttonDown.update();
}

float toVolt(int volt, bool pps = false);
float toAmp(int amp, bool pps = false);

void prepPSU()
{
	PD_UFP.clock_prescale_set(4);
	PD_UFP.init_PPS(PPS_V(15.0), PPS_A(1.0), PD_POWER_OPTION_MAX_POWER);

	unsigned long time = time_us_32();
	while(time_us_32() - time < 1000)
	{
		PD_UFP.run();
		if(PD_UFP.is_PPS_ready())
		{
			ppsReady = true;
			break;
		}
	}

	if(ppsReady)
	{
		// check current
		for(int i = 0; i < PPS_A(5.0); i += PPS_A(0.05))
		{
			if(PD_UFP.set_PPS(PPS_V(5.0), i))
			{
				while(PD_UFP.is_ps_transition())
					PD_UFP.run();
				
				if(PD_UFP.is_PPS_ready())
					maxCurrent = toAmp(PD_UFP.get_current(), ppsReady);
			}
		}

		// check voltage
		for(int i = PPS_V(3.3); i <= PPS_V(21.0); i += PPS_V(1.0))
		{
			if(PD_UFP.set_PPS(i, PPS_A(maxCurrent)))
			{
				while(PD_UFP.is_ps_transition())
					PD_UFP.run();
				
				if(PD_UFP.is_PPS_ready())
					maxVoltage = toVolt(PD_UFP.get_voltage(), ppsReady);
			}
		}
	}
	else
	{
		// check voltage
		PD_UFP.set_power_option(PD_POWER_OPTION_MAX_VOLTAGE);
		while(PD_UFP.is_ps_transition())
			PD_UFP.run();

		maxVoltage = toVolt(PD_UFP.get_voltage(), ppsReady);

		// check current
		PD_UFP.set_power_option(PD_POWER_OPTION_MAX_CURRENT);
		while(PD_UFP.is_ps_transition())
			PD_UFP.run();

		maxCurrent = toAmp(PD_UFP.get_current(), ppsReady);
	}
}

// convert the voltage to the correct values
float toVolt(int volt, bool pps)
{
	float result = 0.0;

	if(pps)
	{
		result = (volt - 0.01) / 50.0;
		result = result < 0 ? 0.0 : result;
	}
	else
	{
		result = (volt - 0.01) / 20.0;
		result = result < 0 ? 0.0 : result;
	}
	
	return result;
}

// convert the current to the correct values
float toAmp(int amp, bool pps)
{
	float result = 0.0;

	if(pps)
	{
		result = (amp - 0.01) / 20.0;
		result = result < 0 ? 0.0 : result;
	}
	else
	{
		result = (amp - 0.01) / 100.0;
		result = result < 0 ? 0.0 : result;
	}

	return result;
}

void request(float* volt, float* current, bool pps)
{
	// if the PPS is ready, request the voltage and current
	if(pps)
	{
		if(*volt <= PPS_V(maxVoltage) && *current <= PPS_A(maxCurrent))
		{
			if(*volt < PPS_V(3.3))
				*volt = PPS_V(3.3);
			if(*current < PPS_A(0.01))
				*current = PPS_A(0.01);

			PD_UFP.set_PPS(*volt, *current);

			while(PD_UFP.is_ps_transition())
				PD_UFP.run();
		}
	}
	else
	{
		// as we dont have PPS, the voltage is fixed to either 5, 9, 12, 15 or 20 volts and we need to find which one is the closest to the requested voltage
		if(*volt <= 5)
			*volt = 5;
		else if(*volt <= 9)
			*volt = 9;
		else if(*volt <= 12)
			*volt = 12;
		else if(*volt <= 15)
			*volt = 15;
		else
			*volt = 20;

		PD_power_option_t option = PDList[(int)((*volt - 5) / 3)];
		PD_UFP.set_power_option(option);

		while(PD_UFP.is_ps_transition())
			PD_UFP.run();
	}
}

/**
 * @brief Main function
 * @note This runs on the core 0
*/
int main()
{
	// setup the microcontroller
	stdio_init_all();
	initI2C();
	initLEDs();
	fetchDataFromEEPROM();

	// setup the ina219 current sensor
	ina219.reset();
	ina219.getData(true);
	ina219.setCalibration();
	ina219.setBusVoltageRange(INA219_BUS_VOLTAGE_RANGE_32V);
	ina219.setGain(INA219_GAIN_320MV);
	ina219.setBusADCResolution(INA219_64SAMPLES_34MS);
	ina219.setShuntADCResolution(INA219_64SAMPLES_34MS);
	ina219.setMode(INA219_MODE_SHUNT_AND_BUS_VOLTAGE_CONTINUOUS);
	ina219.setData();
	ina219.getData(true);

	//PD_UFP.init_PPS(PPS_V(4.20), PPS_A(0.69));
	prepPSU();
	float volt = 20;
	float current = 1;
	request(&volt, &current, ppsReady);

	// create points for important locations
	Point cursor = Point(0, 0);
	Point center = picoGFX.getDisplay().getCenter();
	picoGFX.getPrint().setColor(Colors::White);

	// timer for the framerate calculation
	unsigned long timer = 0, lastTimer = 0;
	double framerate = 0;

	// run the main loop
	while(1)
	{
		ina219.getData();	
		processUSBData();
		RegisterHandler();
		buttonHandler();
		//request(&volt, &current, ppsReady);
		PD_UFP.run();

		// check if serial is ready
		if(tud_cdc_connected())
			PD_UFP.print_status();

		// transfer the data from the INA219 to the registers for external access
		registers.setProtected(Register_Address::Bus_Voltage, ina219.getBusVoltageRaw());
		registers.setProtected(Register_Address::Shunt_Voltage, ina219.getShuntVoltage());
		registers.setProtected(Register_Address::Current, ina219.getCurrentRaw());
		registers.setProtected(Register_Address::Power, ina219.getPowerRaw());

		// if the screen is not ready, we skip the drawing and continue to poll the sensor
		if(!picoGFX.getDisplay().writeReady())
			continue;

		// start measuring the refresh rate, the reason we do this here is because we want to measure the time it takes to draw the screen
		// if this is done earlier, the time it takes to poll the sensors and treat that data, can wrongly be included in the time it takes to draw the screen
		lastTimer = time_us_32();
		// draw the background
		picoGFX.getAdvancedGraphics().drawRotRectGradient(center, display.getWidth(), display.getHeight(), 10, Colors::OrangeRed, Colors::DarkYellow);
		//picoGFX.getAdvancedGraphics().fillGradient(Colors::Derg, Colors::Pink, {50,50}, {320-50, 172-50});
		//picoGFX.getDisplay().fill(Colors::Derg);
		//picoGFX.getGraphics().drawBitmap(background_image, 320, 172);

		picoGFX.getPrint().setCursor(cursor);
		picoGFX.getPrint().setFont(&RobotoMono48);
		picoGFX.getPrint().setColor(Colors::White);

		// draw the current
		picoGFX.getPrint().moveCursor({10,0});
		int current = (ina219.getCurrentRaw() * 100) * CURRENT_RESOLUTION;
		// it overflows if the current is zero for some reason, so we manually set it to zero if that happens
		current = current > 5000 ? 0 : current;
		int current_int = current / 100;
		int current_fraction = current_int > 10 ? (current % 10) : (current % 100);
		picoGFX.getPrint().print(current_int);
		picoGFX.getPrint().print(".");
		// if the current is less than 10, we need to draw a zero
		if(current_int < 10 && current_fraction != 0)
			picoGFX.getPrint().print("0");
		picoGFX.getPrint().print(current_fraction);
		// draw additional zeros if needed
		if(current_fraction == 0)
			picoGFX.getPrint().print("0");
		picoGFX.getPrint().println("A");

		// draw the voltage
		picoGFX.getPrint().moveCursor({10, 0});
		int volt = ina219.getBusVoltageRaw() * 100 * BUS_VOLTAGE_LSB_VALUE;
		int volt_int = volt / 100;
		int volt_fraction = volt_int > 10 ? (volt % 10) : (volt % 100);
		picoGFX.getPrint().print(volt_int);
		picoGFX.getPrint().print(".");
		// if the current is less than 10, we need to draw a zero
		if(volt_fraction < 10 && volt_fraction != 0)
			picoGFX.getPrint().print("0");
		picoGFX.getPrint().print(volt_fraction);
		// draw additional zeros if needed
		if(volt_fraction == 0)
			picoGFX.getPrint().print("0");
		picoGFX.getPrint().println("V");

		// draw the power
		picoGFX.getPrint().moveCursor({10,0});
		int power = (ina219.getPowerRaw() * 2000) * CURRENT_RESOLUTION;
		int power_int = power / 100;
		int power_fraction = power_int > 10 ? (power % 10) : (power % 100);
		picoGFX.getPrint().print(power_int);
		picoGFX.getPrint().print(".");
		// if the current is less than 10, we need to draw a zero
		if(power_fraction < 10 && power_fraction != 0)
			picoGFX.getPrint().print("0");
		picoGFX.getPrint().print(power_fraction);
		// draw additional zeros if needed
		if(power_fraction == 0)
			picoGFX.getPrint().print("0");
		picoGFX.getPrint().print("W\n");

		// draw the frame counter
		picoGFX.getPrint().setCursor({230, 10});
		picoGFX.getPrint().setColor(Colors::GreenYellow);
		picoGFX.getPrint().setFont(&ComicSans24);
		picoGFX.getPrint().print(framerate);

		// output the data to the display
		picoGFX.getDisplay().update();

		// reset the timer
		timer = time_us_32() - lastTimer;
		framerate = 1000000.0 / timer;
	}
}

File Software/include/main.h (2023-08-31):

// This is a header guard. It prevents the file from being included more than once.
#pragma once

/***
 *      ____  _           
 *     |  _ \(_)_ __  ___ 
 *     | |_) | | '_ \/ __|
 *     |  __/| | | | \__ \
 *     |_|   |_|_| |_|___/
 *                        
 */

// I2C bus that the EEPROM and INA219 are connected to
#define I2C0_SDA            12
#define I2C0_SCL            13

// I2C bus that the FUSB302 is connected to
#define I2C1_SDA            2
#define I2C1_SCL            3
#define PIN_FUSB302_INT     4

// Display pins
#define DISP_PIN_DC         16
#define DISP_PIN_CS         17
#define DISP_PIN_SCK        18
#define DISP_PIN_MOSI       19
#define DISP_PIN_RST        20
#define DISP_PIN_BL         21

// Button pins
#define BUTTON_UP           9
#define BUTTON_MENU         10
#define BUTTON_DOWN         11

// Mosfet pins and LEDs
#define LEFT_MOSFET_LED     15
#define LEFT_MOSFET         14
#define RIGHT_MOSFET_LED    25
#define RIGHT_MOSFET        24



/***
 *     __     __         _       _     _           
 *     \ \   / /_ _ _ __(_) __ _| |__ | | ___  ___ 
 *      \ \ / / _` | '__| |/ _` | '_ \| |/ _ \/ __|
 *       \ V / (_| | |  | | (_| | |_) | |  __/\__ \
 *        \_/ \__,_|_|  |_|\__,_|_.__/|_|\___||___/
 *                                                 
 */

// Display constants
#define DISP_WIDTH          172     // 172 pixels wide
#define DISP_HEIGHT         320     // 320 pixels tall
#define DISP_OFFSET_X0      0       // cut off on the left side of the display
#define DISP_OFFSET_X1      0       // cut off on the right side of the display
#define DISP_OFFSET_Y0      34      // cut off on the top of the display
#define DISP_OFFSET_Y1      34      // ut off on the bottom of the display
#define DISP_ROTATION       3       // 0, 1, 2, or 3

// I2C constants
#define I2C0_SPEED          1000000  // 1 MHz
#define I2C1_SPEED          100000  // 1 MHz

// System constants
#define MULTICORE_FLAG_VALUE        0x69



/***
 *         _       _     _                             
 *        / \   __| | __| |_ __ ___  ___ ___  ___  ___ 
 *       / _ \ / _` |/ _` | '__/ _ \/ __/ __|/ _ \/ __|
 *      / ___ \ (_| | (_| | | |  __/\__ \__ \  __/\__ \
 *     /_/   \_\__,_|\__,_|_|  \___||___/___/\___||___/
 *                                                     
 */

#define FUSB302_ADDRESS     0x22
#define INA219_ADDRESS      0x40
#define EEPROM_ADDRESS      0x50



/***
 *      ___            _           _           
 *     |_ _|_ __   ___| |_   _  __| | ___  ___ 
 *      | || '_ \ / __| | | | |/ _` |/ _ \/ __|
 *      | || | | | (__| | |_| | (_| |  __/\__ \
 *     |___|_| |_|\___|_|\__,_|\__,_|\___||___/
 *                                             
 */

#include <stdio.h>
#include "pico/stdlib.h"
#include "pico/bootrom.h"
#include "pico/binary_info.h"
#include "pico/time.h"
#include "tusb.h"

#include "hardware/uart.h"
#include "hardware/i2c.h"
#include "hardware/watchdog.h"

#include "Button.hpp"
#include "INA219.hpp"
#include "Memory.hpp"
#include "version.h"
#include "Registers.hpp"
#include "PicoGFX.hpp"
#include "ST7789.hpp"
#include "RobotoMono24.font"
#include "RobotoMono48.font"
#include "bg.h"
#include "test.h"

/***
 *      ____  _         _____           _    ____        _        
 *     |  _ \(_) ___ __|_   _|__   ___ | |  |  _ \  __ _| |_ __ _ 
 *     | |_) | |/ __/ _ \| |/ _ \ / _ \| |  | | | |/ _` | __/ _` |
 *     |  __/| | (_| (_) | | (_) | (_) | |  | |_| | (_| | || (_| |
 *     |_|   |_|\___\___/|_|\___/ \___/|_|  |____/ \__,_|\__\__,_|
 *                                                               
 */

bi_decl(bi_program_name("USB-PD Power Supply"));
bi_decl(bi_program_description("Your own USB-PD variable power supply with an active circuit breaker."));
bi_decl(bi_program_version_string(GIT_COMMIT_HASH));
bi_decl(bi_program_url("https://github.com/Cuprum77/PD2Breadboard"));

bi_decl(bi_4pins_with_names(DISP_PIN_CS, "SPI Chip Select", DISP_PIN_SCK, "SPI Clock", DISP_PIN_MOSI, "SPI Data", DISP_PIN_RST, "SPI Reset"));
bi_decl(bi_2pins_with_names(DISP_PIN_DC, "SPI Data Control", DISP_PIN_BL, "Display Backlight"));
bi_decl(bi_3pins_with_names(BUTTON_UP, "Button Up", BUTTON_MENU, "Button Menu", BUTTON_DOWN, "Button Down"));
bi_decl(bi_1pin_with_name(PIN_FUSB302_INT, "USB-PD Interrupt"));

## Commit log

2023-04-09 rename to fix case issue
2023-04-09 Linux fixes thanks to https://github.com/diminDDL
    [programmer.py]
2023-04-21 forgot to keep track of the polling time
2023-04-26 abstraction part of driver complete
2023-04-26 fixed cmake to allow include
    [Defines.hpp, main.cpp]
2023-05-03 PCB specific changes
2023-05-09 rev 2
    [Buttons.kicad_sch, Display.kicad_sch, EEPROM.kicad_sch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]
2023-05-10 minor tweaks
    [RP2040.kicad_sch]
2023-05-11 removed problematic printf
2023-05-30 still cant get PD to work properly ¯\_(ツ)_/¯
2023-06-08 started on pcb design
    [Display.kicad_sch, MOSFETs.kicad_sch, RP2040.kicad_sch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]
2023-06-08 small changes
    [USB-PD.kicad_pcb, USB.kicad_sch]
2023-06-13 minor work
    [USB-PD.kicad_pcb, USB-PD.kicad_sch]
2023-06-22 smaller tweaks
    [MOSFETs.kicad_sch, USB-PD.kicad_pcb]
